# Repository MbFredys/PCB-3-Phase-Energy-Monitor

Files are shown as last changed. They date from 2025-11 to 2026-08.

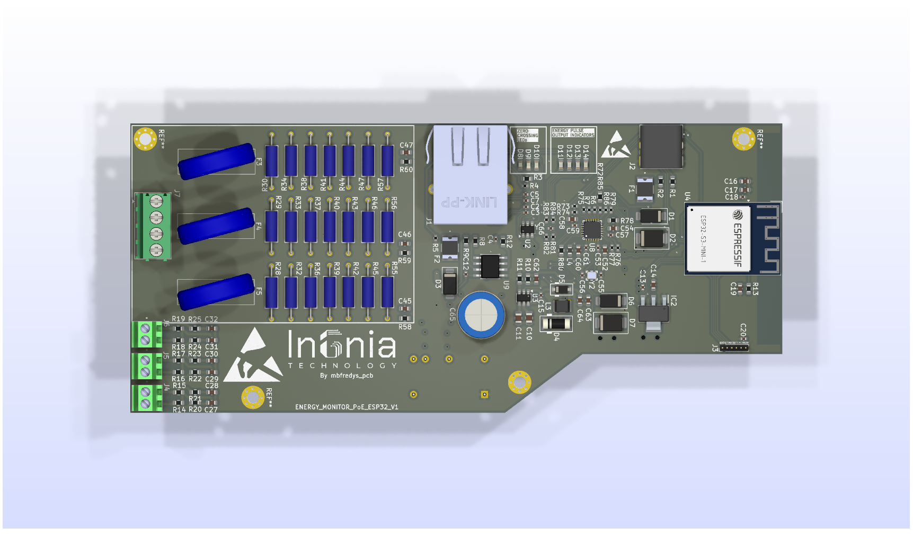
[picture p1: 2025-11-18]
Release/topview_2.png

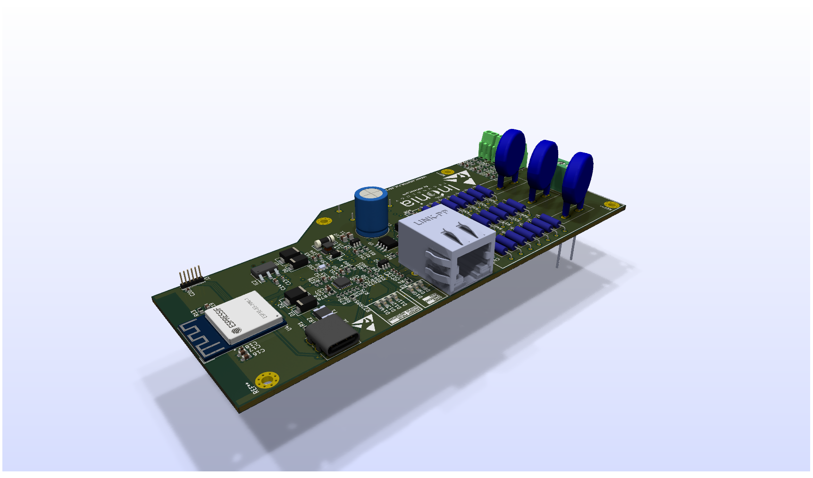
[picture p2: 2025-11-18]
Release/3dview_2.png

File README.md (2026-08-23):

# Three-Phase Energy Monitor



Hardware design for a three-phase, four-wire energy-monitoring platform with Ethernet and Power over Ethernet, intended for future integration with building-management systems.

> **Project status:** Design and manufacturing documentation completed. The PCB has not been fabricated, calibrated, electrically validated, or tested for regulatory compliance.

## Project objective

The project explores an open and documented architecture capable of acquiring three-phase electrical measurements and exposing them through a connected embedded platform.

## System architecture

- **Measurement:** ATM90E32AS for 3P4W energy measurement
- **Controller:** ESP32-S3-MINI-1
- **Networking:** LAN8720A Ethernet PHY using RMII
- **Power:** TPS2378 PoE interface with local 5 V and 3.3 V rails
- **Sensing:** External current transformers and resistive voltage-sensing networks
- **Isolation:** Digital isolators between measurement and low-voltage digital domains
- **Development access:** USB and debugging/programming interfaces

## Engineering work

- Defined system requirements and functional architecture
- Selected the principal ICs, protection devices, connectors, and power components
- Developed the schematic and multi-domain PCB layout in KiCad
- Defined measurement, isolation, Ethernet, PoE, and power-distribution sections
- Prepared the BOM and manufacturing documentation

## Key design considerations

- Isolation boundaries and return-current paths
- Creepage and clearance around mains-related circuitry
- Mixed-signal grounding and decoupling
- Ethernet differential routing and PHY termination
- PoE power conversion and protection
- Calibration strategy for voltage and current channels

## Deliverables

The repository contains the available design source files and supporting manufacturing documentation. Review the repository structure before using any generated outputs.

## Validation still required

A physical prototype is required to verify:

- Electrical safety and isolation distances
- Measurement accuracy and calibration
- Ethernet and PoE operation
- Thermal behavior and power integrity
- EMC/EMI performance
- Compliance with any applicable product or installation standards

This repository should be treated as an engineering design project, not as a certified or production-ready energy meter.

## License

Licensed under CERN-OHL-W-2.0.

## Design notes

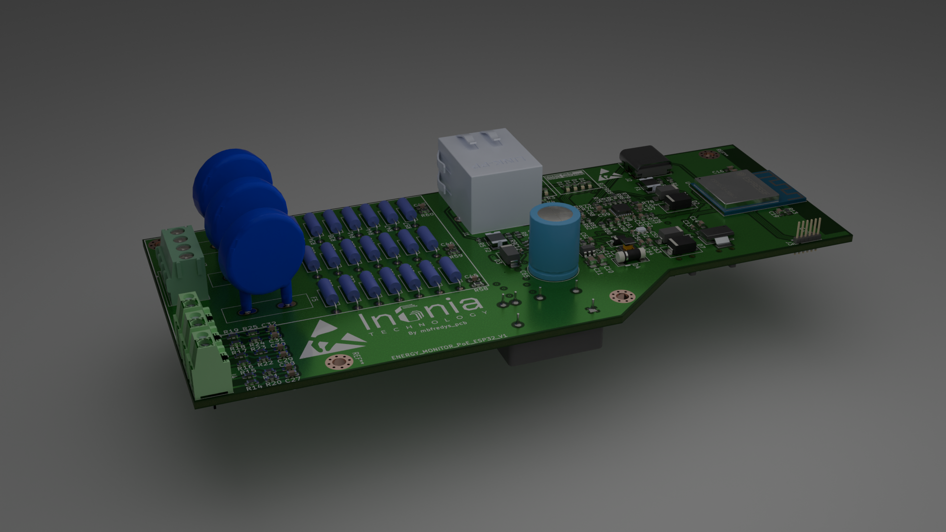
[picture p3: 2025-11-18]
Release/3D_HIGH_QUALITY.png

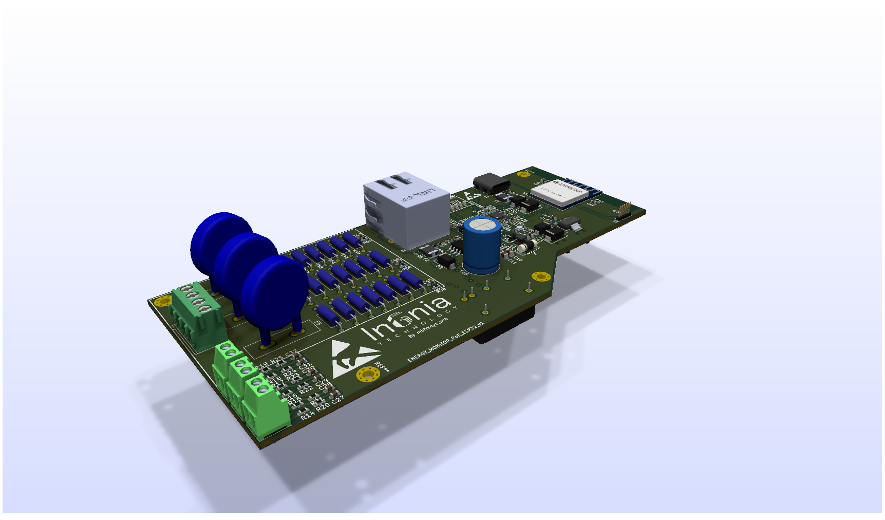
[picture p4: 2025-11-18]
Release/3dview.png

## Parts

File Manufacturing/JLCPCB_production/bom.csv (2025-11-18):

Designator | Footprint | Quantity | Value | LCSC Part #
C1, C12, C13, C15, C18, C20, C25, C26, C34, C35, C39, C4, C41, C42, C48, C49, C57, C66 | 0402 | 18 | 0.1uF
C10, C11 | 0805 | 2 | 10uF
C14, C16, C21, C36, C37, C43, C44, C50, C51, C54, C6, C63, C64 | 0603 | 13 | 10uF
C17, C19, C52, C58, C60 | 0603 | 5 | 1uF
C2, C23, C24, C3, C5, C55, C56, C7 | 0402 | 8 | 10pF
C22 | 0603 | 1 | 4.7uF
C27, C28, C29, C30, C31, C32, C33, C38, C40, C45, C46, C47 | 0603 | 12 | 18nF
C53, C59, C61 | 0402 | 3 | 470pF
C62 | 0603 | 1 | 20pF
C65 | C_Radial_D10.0mm_H12.5mm_P5.00mm | 1 | 22uF
C8, C9 | 0603 | 2 | 2.2uF
D1, D6 | D_SMA | 2 | SS14
D10, D11, D12, D13, D14, D8, D9 | 0603 | 7 | LEDs
D2, D7 | D_SMB_TVS | 2 | SMBJ5.0CA
D3 | D_SMA | 1 | SMAJ58A
D4 | D_MELF | 1 | SM360
D5 | D_SOD-123 | 1 | 1N4148W
F1 | FUSE_1812L05060_LTF | 1 | 1812L110PR
F2 | FUSE_1812L05060_LTF | 1 | 1812L050/60MR
F3, F4, F5 | MOV14D471K | 3 | MOV14D471K
IC1, IC2 | SOT230P700X180-4N | 2 | LD1117-3.3V
J1 | MagJack_PoE_RJ45 | 1 | RJ45_PoE
J2 | USB_C_Receptacle_GCT_USB4085 | 1 | USB_C_Receptacle_USB2.0_14P
J3 | PinHeader_1x06_P1.00mm_Vertical | 1 | Pin Header
J4, J5, J6 | TE_282834-2 | 3 | Screw_Terminal_01x02
J7 | TerminalBlock_Phoenix_PT-1,5-4-3.5-H_1x04_P3.50mm_Horizontal | 1 | Screw_Conn
L1, L2, L3 | FUSE_MF-USMFLAB | 3 | 22uH
L4 | 0603 | 1 | FerriteBead
R1, R2 | 0603 | 2 | 5.1k
R10 | 0603 | 1 | 52.3k
R11, R12, R13, R3, R31, R61, R78 | 0603 | 7 | 10k
R14, R15, R16, R17, R18, R19 | 0603 | 6 | 2.4
R20, R21, R22, R23, R24, R25, R26, R27, R35, R58, R59, R60 | 0603 | 12 | 1k
R28, R29, R30, R32, R33, R34, R36, R37, R38, R39, R40, R41, R42, R43, R44, R45, R46, R47, R55, R56, R57 | RES_09FCT00_VIS | 21 | 240k
R4, R5 | 0402 | 2 | 270
R48, R49, R50, R51, R6, R62, R63, R64, R7, R73, R74, R75, R76, R77, R79, R85, R86 | 0402 | 17 | 33
R52, R53, R54, R65, R66, R67, R68, R69, R70, R71 | 0402 | 10 | 510
R72 | 0603 | 1 | 2.2k
R8 | 0603 | 1 | 24.9k
R80 | 0603 | 1 | 12.1k
R81, R82, R83, R84 | 0402 | 4 | 50
R9 | 0603 | 1 | 63.4
SW1, SW2 | SW_SPDT_PCM12 | 2 | SW_SPDT
U1 | Converter_DCDC_Murata_NMAxxxxDC_THT | 1 | NMA0505DC
U2 | SOT-23-6 | 1 | WE-TVS-824015043
U3 | SOT-23-6 | 1 | MCP16331x-xCH
U4 | ESP32-S2-MINI-1 | 1 | ESP32-S3-MINI-1
U5 | TQFP48_7x7MC_MCH | 1 | ATM90E32AS-AU-Y
U6 | SOIC-16W_7.5x10.3mm_P1.27mm | 1 | Si8660ED-AS
U7 | SOIC-16W_7.5x10.3mm_P1.27mm | 1 | Si8641ED-B-IS
U8 | LAN8720A | 1 | LAN8720A
U9 | DDA8_3P1X2P4_TEX-M | 1 | TPS2378DDAR
Y1 | Crystal_SMD_2.0x1.6mm | 1 | 16MHz
Y2 | Crystal_SMD_2.0x1.6mm | 1 | 25MHz

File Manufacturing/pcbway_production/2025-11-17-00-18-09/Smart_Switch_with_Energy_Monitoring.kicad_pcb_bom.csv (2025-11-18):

Designator | Quantity | Value | Footprint | Package | MPN | DNP | Mount_Type
C1, C12, C13, C15, C18, C20, C25, C26, C34, C35, C39, C4, C41, C42, C48, C49, C57, C66 | 18 | 0.1uF | C_0402_1005Metric |  |  |  | smt
C10, C11 | 2 | 10uF | C_0805_2012Metric |  |  |  | smt
C14, C16, C21, C36, C37, C43, C44, C50, C51, C54, C6, C63, C64 | 13 | 10uF | C_0603_1608Metric |  |  |  | smt
C17, C19, C52, C58, C60 | 5 | 1uF | C_0603_1608Metric |  |  |  | smt
C2, C23, C24, C3, C5, C55, C56, C7 | 8 | 10pF | C_0402_1005Metric |  |  |  | smt
C22 | 1 | 4.7uF | C_0603_1608Metric |  |  |  | smt
C27, C28, C29, C30, C31, C32, C33, C38, C40, C45, C46, C47 | 12 | 18nF | C_0603_1608Metric |  |  |  | smt
C53, C59, C61 | 3 | 470pF | C_0402_1005Metric |  |  |  | smt
C62 | 1 | 20pF | C_0603_1608Metric |  |  |  | smt
C65 | 1 | 22uF | C_Radial_D10.0mm_H12.5mm_P5.00mm |  |  |  | tht
C8, C9 | 2 | 2.2uF | C_0603_1608Metric |  |  |  | smt
D1, D6 | 2 | SS14 | D_SMA |  |  |  | smt
D10, D11, D12, D13, D14, D8, D9 | 7 | LEDs | LED_0603_1608Metric |  |  |  | smt
D2, D7 | 2 | SMBJ5.0CA | D_SMB_TVS |  |  |  | smt
D3 | 1 | SMAJ58A | D_SMA |  |  |  | smt
D4 | 1 | SM360 | D_MELF |  |  |  | smt
D5 | 1 | 1N4148W | D_SOD-123 |  |  |  | smt
F1 | 1 | 1812L110PR | FUSE_1812L05060_LTF |  |  |  | smt
F2 | 1 | 1812L050/60MR | FUSE_1812L05060_LTF |  |  |  | smt
F3, F4, F5 | 3 | MOV14D471K | MOV14D471K |  |  |  | tht
IC1, IC2 | 2 | LD1117-3.3V | SOT230P700X180-4N |  |  |  | smt
J1 | 1 | RJ45_PoE | MagJack_PoE_RJ45 |  |  |  | tht
J2 | 1 | USB_C_Receptacle_USB2.0_14P | USB_C_Receptacle_GCT_USB4085 |  |  |  | tht
J3 | 1 | Pin Header | PinHeader_1x06_P1.00mm_Vertical |  |  |  | tht
J4, J5, J6 | 3 | Screw_Terminal_01x02 | TE_282834-2 |  |  |  | tht
J7 | 1 | Screw_Conn | TerminalBlock_Phoenix_PT-1,5-4-3.5-H_1x04_P3.50mm_Horizontal |  |  |  | tht
L1, L2, L3 | 3 | 22uH | FUSE_MF-USMFLAB |  |  |  | smt
L4 | 1 | FerriteBead | L_0603_1608Metric |  |  |  | smt
R1, R2 | 2 | 5.1k | R_0603_1608Metric |  |  |  | smt
R10 | 1 | 52.3k | R_0603_1608Metric |  |  |  | smt
R11, R12, R13, R3, R31, R61, R78 | 7 | 10k | R_0603_1608Metric |  |  |  | smt
R14, R15, R16, R17, R18, R19 | 6 | 2.4 | R_0603_1608Metric |  |  |  | smt
R20, R21, R22, R23, R24, R25, R26, R27, R35, R58, R59, R60 | 12 | 1k | R_0603_1608Metric |  |  |  | smt
R28, R29, R30, R32, R33, R34, R36, R37, R38, R39, R40, R41, R42, R43, R44, R45, R46, R47, R55, R56, R57 | 21 | 240k | RES_09FCT00_VIS |  |  |  | tht
R4, R5 | 2 | 270 | R_0402_1005Metric |  |  |  | smt
R48, R49, R50, R51, R6, R62, R63, R64, R7, R73, R74, R75, R76, R77, R79, R85, R86 | 17 | 33 | R_0402_1005Metric |  |  |  | smt
R52, R53, R54, R65, R66, R67, R68, R69, R70, R71 | 10 | 510 | R_0402_1005Metric |  |  |  | smt
R72 | 1 | 2.2k | R_0603_1608Metric |  |  |  | smt
R8 | 1 | 24.9k | R_0603_1608Metric |  |  |  | smt
R80 | 1 | 12.1k | R_0603_1608Metric |  |  |  | smt
R81, R82, R83, R84 | 4 | 50 | R_0402_1005Metric |  |  |  | smt
R9 | 1 | 63.4 | R_0603_1608Metric |  |  |  | smt
SW1, SW2 | 2 | SW_SPDT | SW_SPDT_PCM12 |  |  |  | smt
U1 | 1 | NMA0505DC | Converter_DCDC_Murata_NMAxxxxDC_THT |  |  |  | tht
U2 | 1 | WE-TVS-824015043 | SOT-23-6 |  |  |  | smt
U3 | 1 | MCP16331x-xCH | SOT-23-6 |  |  |  | smt
U4 | 1 | ESP32-S3-MINI-1 | ESP32-S2-MINI-1 |  |  |  | smt
U5 | 1 | ATM90E32AS-AU-Y | TQFP48_7x7MC_MCH |  |  |  | smt
U6 | 1 | Si8660ED-AS | SOIC-16W_7.5x10.3mm_P1.27mm |  |  |  | smt
U7 | 1 | Si8641ED-B-IS | SOIC-16W_7.5x10.3mm_P1.27mm |  |  |  | smt
U8 | 1 | LAN8720A | LAN8720A |  |  |  | smt
U9 | 1 | TPS2378DDAR | DDA8_3P1X2P4_TEX-M |  |  |  | smt
Y1 | 1 | 16MHz | Crystal_SMD_2.0x1.6mm |  |  |  | smt
Y2 | 1 | 25MHz | Crystal_SMD_2.0x1.6mm |  |  |  | smt

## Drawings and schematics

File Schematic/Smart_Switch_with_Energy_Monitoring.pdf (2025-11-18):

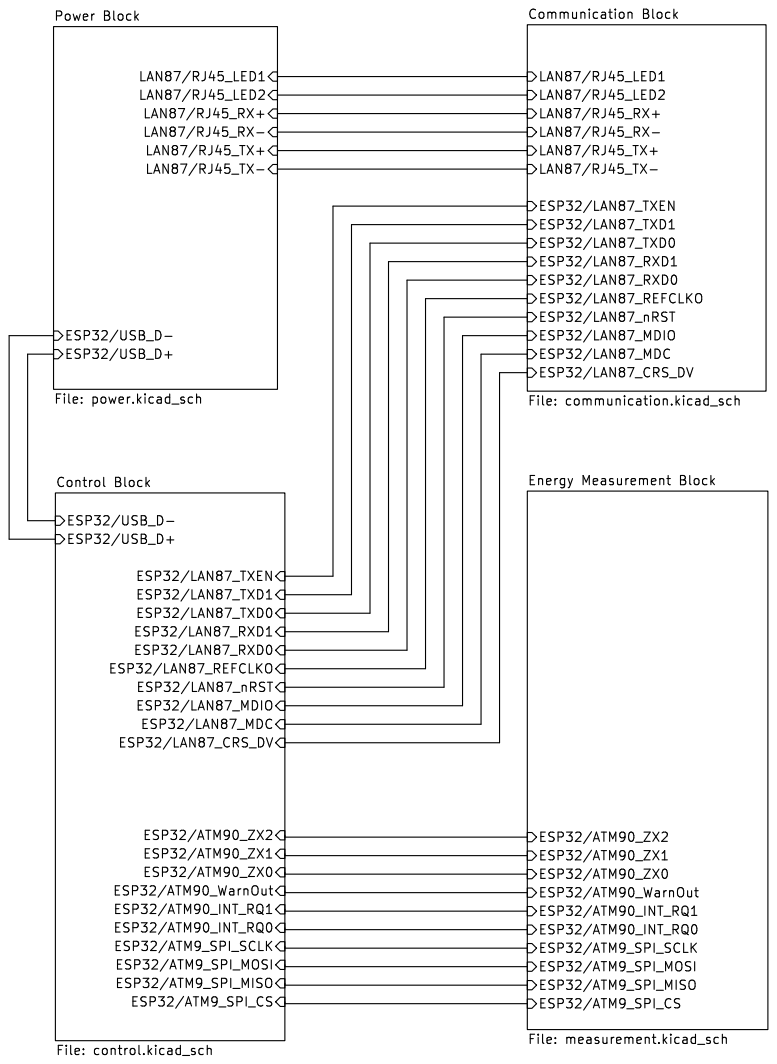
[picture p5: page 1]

Id: 1/5 Title: Office Energy Monitor File: Smart_Switch_with_Energy_Monitoring.kicad_sch Sheet: /

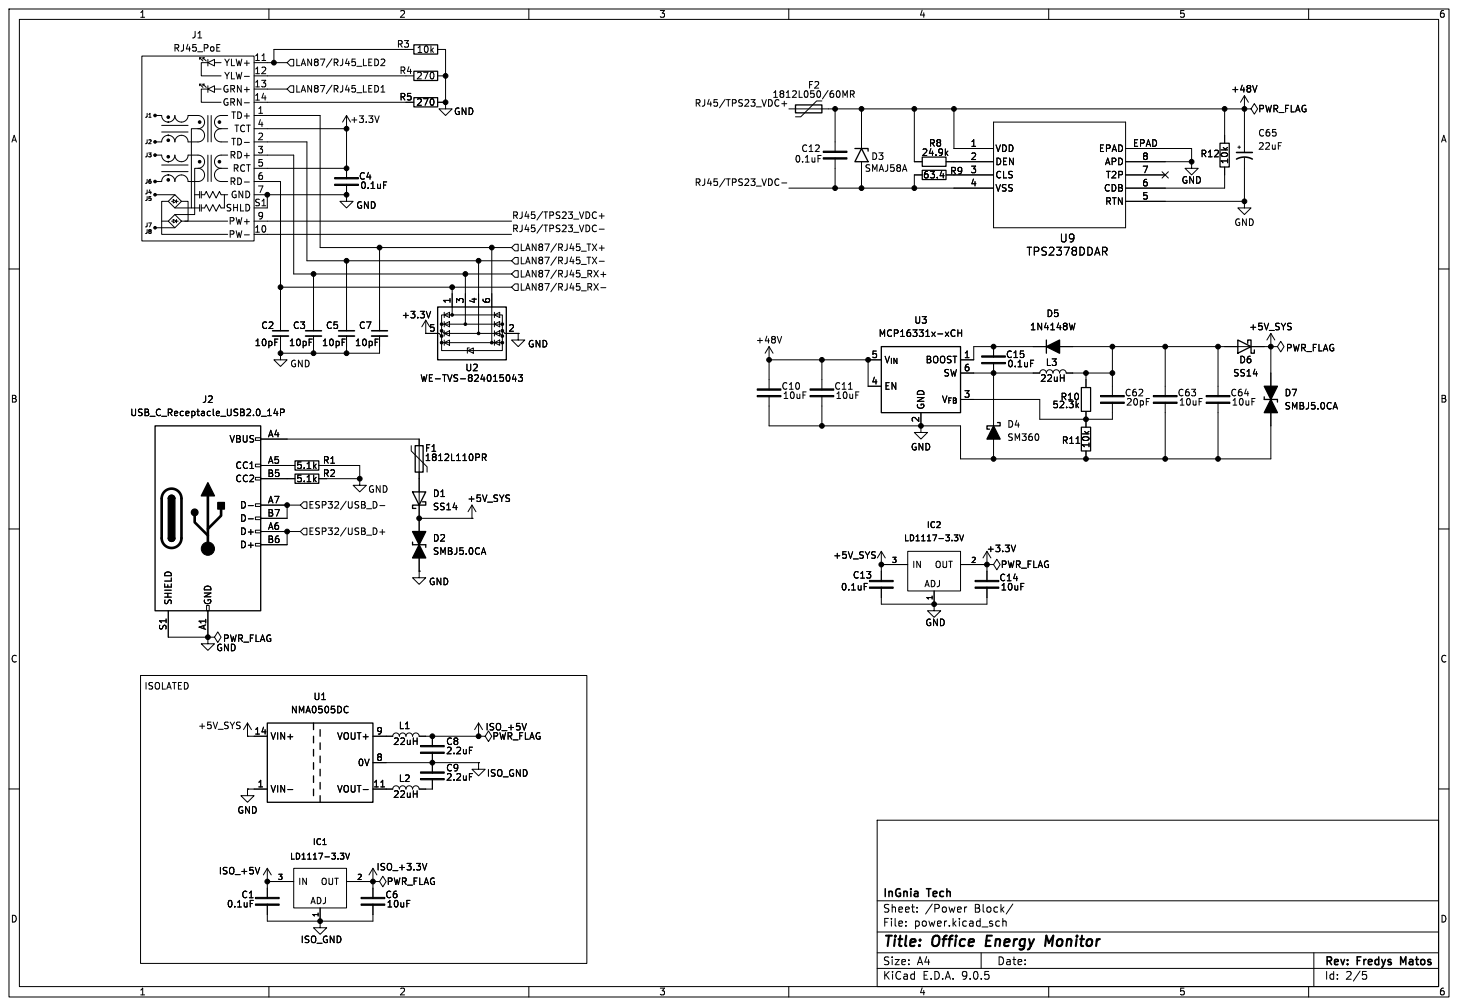
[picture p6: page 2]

2 BOOST 1 SW 6 V_{FB}3 U3 MCP16331x-xCH

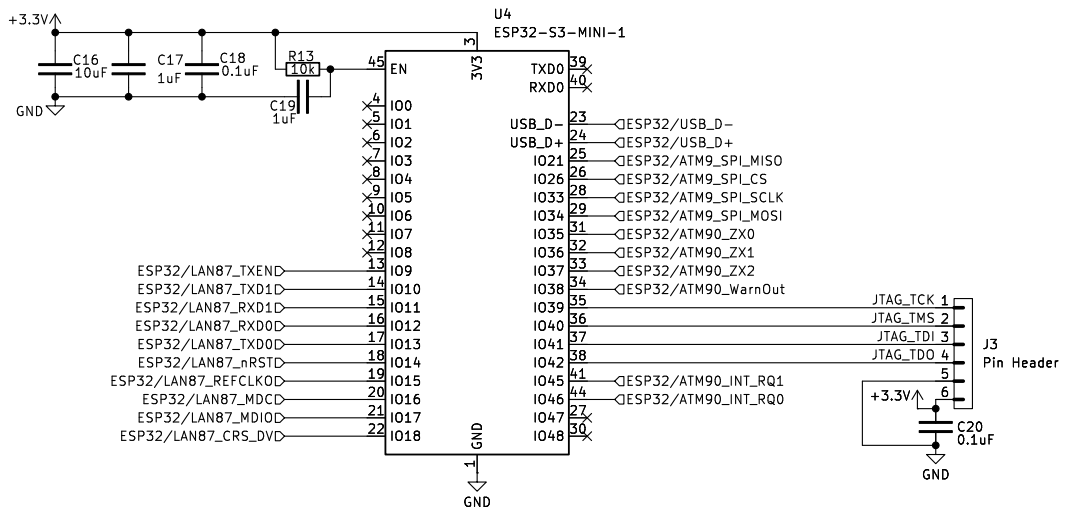
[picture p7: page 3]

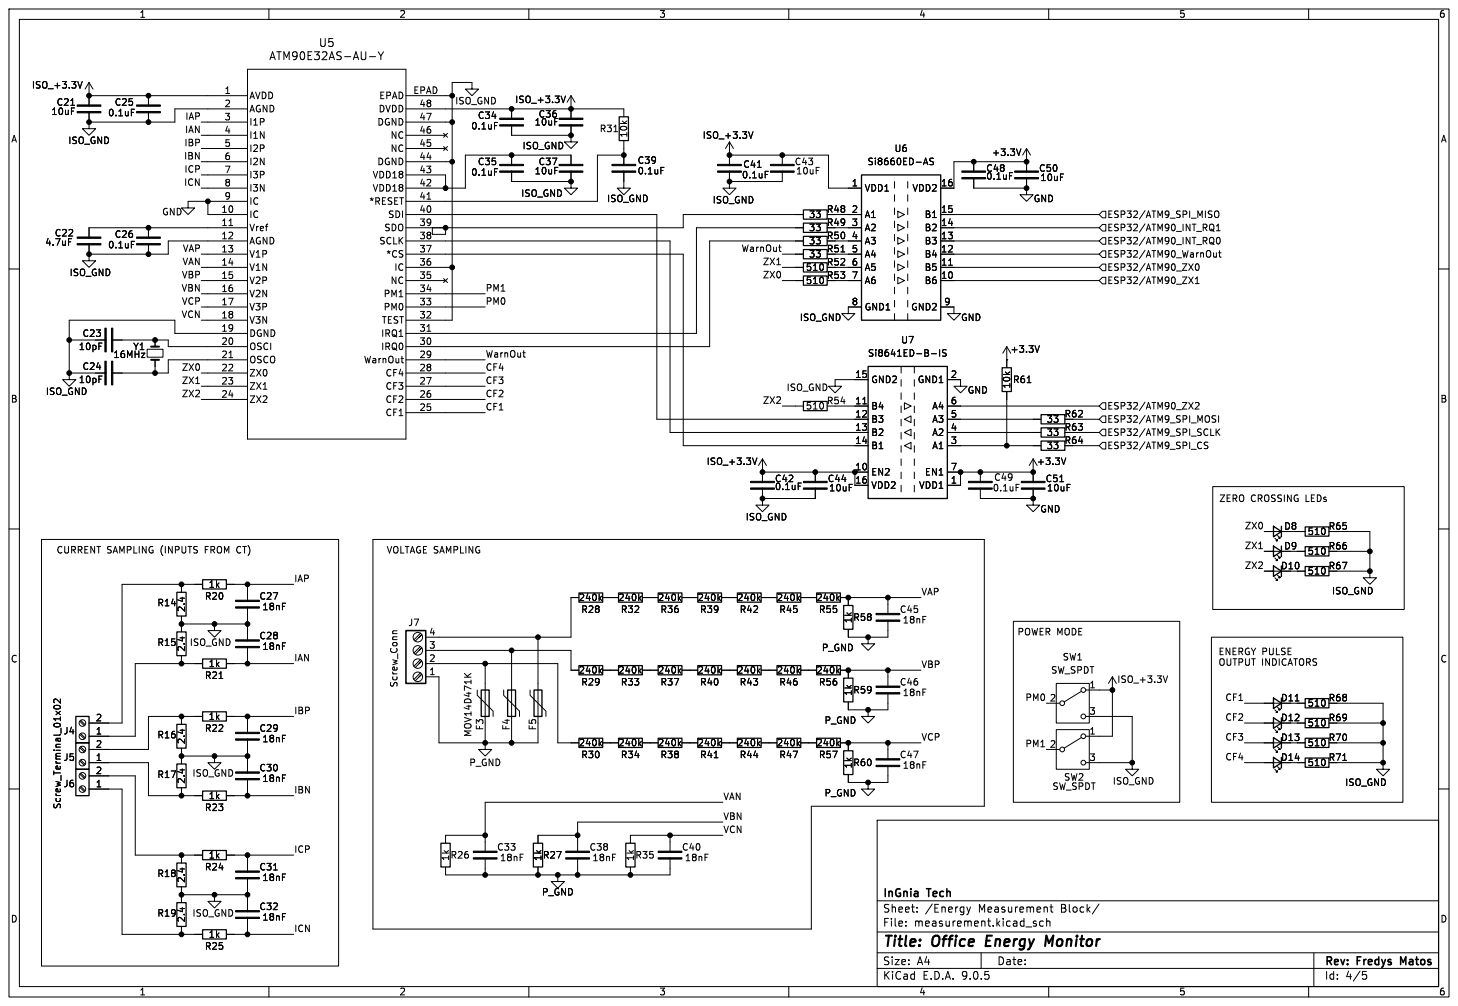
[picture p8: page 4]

ZERO CROSSING LEDs POWER MODE

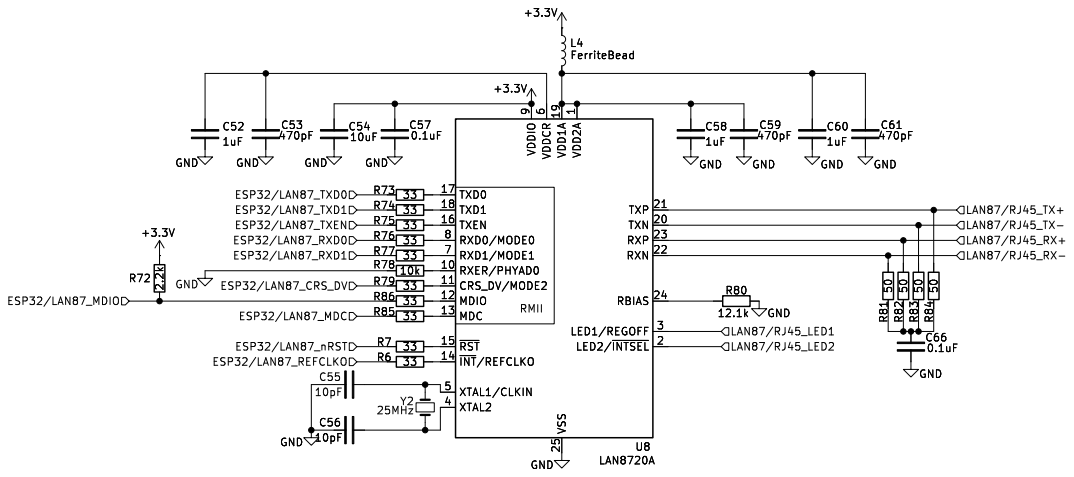
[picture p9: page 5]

1 TXP 21 TXN 20 RXP 23 RXN 22 RBIAS 24

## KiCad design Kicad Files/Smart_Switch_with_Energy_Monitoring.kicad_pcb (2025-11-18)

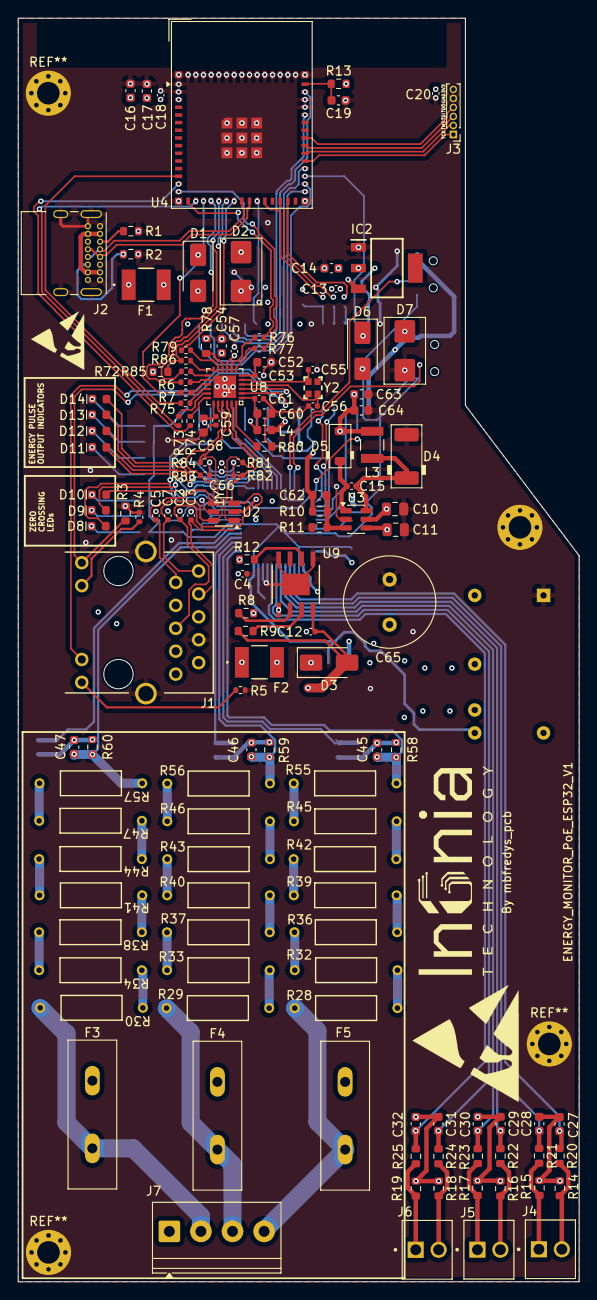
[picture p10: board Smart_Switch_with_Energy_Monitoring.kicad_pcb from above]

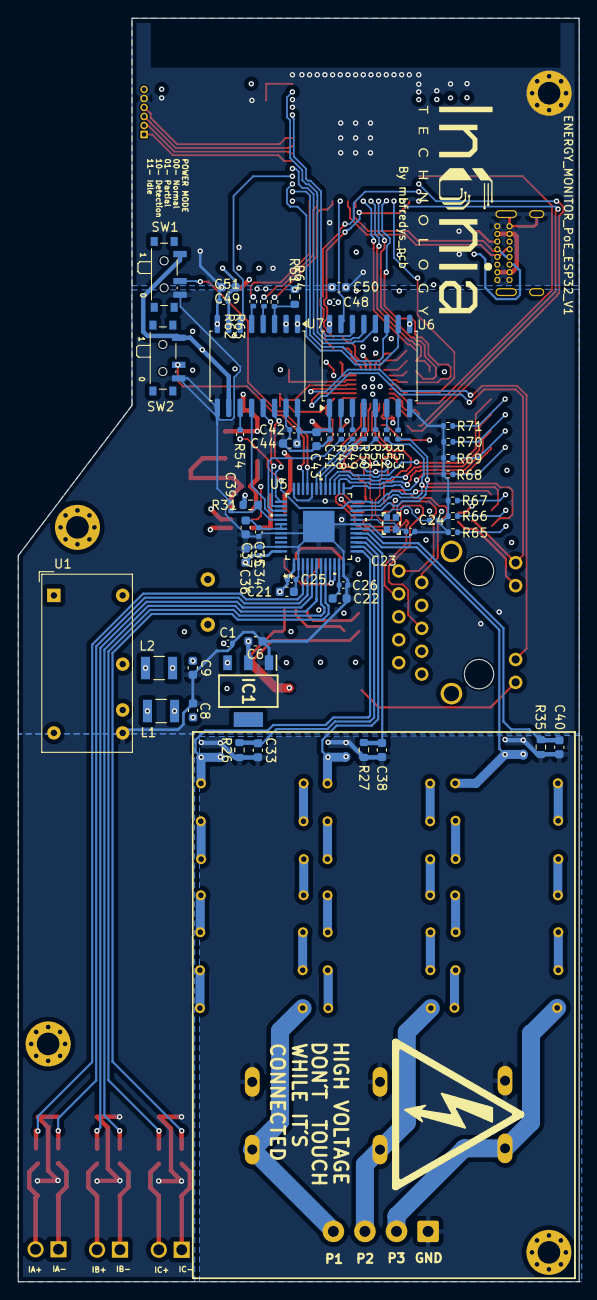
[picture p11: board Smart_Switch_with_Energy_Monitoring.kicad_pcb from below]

Board: 4 copper layers, 62.1 x 140.0 mm, 197 parts (58 on the bottom side), 153 nets.

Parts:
C1, C4, C12, C13, C15, C18, C20, C25, C26, C34, C35, C39, C41, C42, C48, C49, C57, C66: 0.1uF; C_0402_1005Metric
C2, C3, C5, C7, C23, C24, C55, C56: 10pF; C_0402_1005Metric
C6, C14, C16, C21, C36, C37, C43, C44, C50, C51, C54, C63, C64: 10uF; C_0603_1608Metric
C8, C9: 2.2uF; C_0603_1608Metric
C10, C11: 10uF; C_0805_2012Metric
C17, C19, C52, C58, C60: 1uF; C_0603_1608Metric
C22: 4.7uF; C_0603_1608Metric
C27, C28, C29, C30, C31, C32, C33, C38, C40, C45, C46, C47: 18nF; C_0603_1608Metric
C53, C59, C61: 470pF; C_0402_1005Metric
C62: 20pF; C_0603_1608Metric
C65: 22uF; C_Radial_D10.0mm_H12.5mm_P5.00mm
D1, D6: SS14; D_SMA
D2, D7: SMBJ5.0CA; D_SMB_TVS
D3: SMAJ58A; D_SMA
D4: SM360; D_MELF
D5: 1N4148W; D_SOD-123
D8, D9, D10, D11, D12, D13, D14: LEDs; LED_0603_1608Metric
F1: 1812L110PR; FUSE_1812L05060_LTF
F2: 1812L050/60MR; FUSE_1812L05060_LTF
F3, F4, F5: MOV14D471K
IC1, IC2: LD1117-3.3V; SOT230P700X180-4N
J1: RJ45_PoE; MagJack_PoE_RJ45
J2: USB_C_Receptacle_USB2.0_14P; USB_C_Receptacle_GCT_USB4085
J3: Pin Header; PinHeader_1x06_P1.00mm_Vertical
J4, J5, J6: Screw_Terminal_01x02; TE_282834-2
J7: Screw_Conn; TerminalBlock_Phoenix_PT-1,5-4-3.5-H_1x04_P3.50mm_Horizontal
L1, L2, L3: 22uH; FUSE_MF-USMFLAB
L4: FerriteBead; L_0603_1608Metric
R1, R2: 5.1k; R_0603_1608Metric
R3, R11, R12, R13, R31, R61, R78: 10k; R_0603_1608Metric
R4, R5: 270; R_0402_1005Metric
R6, R7, R48, R49, R50, R51, R62, R63, R64, R73, R74, R75, R76, R77, R79, R85, R86: 33; R_0402_1005Metric
R8: 24.9k; R_0603_1608Metric
R9: 63.4; R_0603_1608Metric
R10: 52.3k; R_0603_1608Metric
R14, R15, R16, R17, R18, R19: 2.4; R_0603_1608Metric
R20, R21, R22, R23, R24, R25, R26, R27, R35, R58, R59, R60: 1k; R_0603_1608Metric
R28, R29, R30, R32, R33, R34, R36, R37, R38, R39, R40, R41, R42, R43, R44, R45, R46, R47, R55, R56, R57: 240k; RES_09FCT00_VIS
R52, R53, R54, R65, R66, R67, R68, R69, R70, R71: 510; R_0402_1005Metric
R72: 2.2k; R_0603_1608Metric
R80: 12.1k; R_0603_1608Metric
R81, R82, R83, R84: 50; R_0402_1005Metric
SW1, SW2: SW_SPDT; SW_SPDT_PCM12
U1: NMA0505DC; Converter_DCDC_Murata_NMAxxxxDC_THT
U2: WE-TVS-824015043; SOT-23-6
U3: MCP16331x-xCH; SOT-23-6
U4: ESP32-S3-MINI-1; ESP32-S2-MINI-1
U5: ATM90E32AS-AU-Y; TQFP48_7x7MC_MCH
U6: Si8660ED-AS; SOIC-16W_7.5x10.3mm_P1.27mm
U7: Si8641ED-B-IS; SOIC-16W_7.5x10.3mm_P1.27mm
U8: LAN8720A
U9: TPS2378DDAR; DDA8_3P1X2P4_TEX-M
Y1: 16MHz; Crystal_SMD_2.0x1.6mm
Y2: 25MHz; Crystal_SMD_2.0x1.6mm

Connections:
+3.3V: C4.2, C14.2, C16.2, C17.2, C18.2, C20.2, C48.2, C49.2, C50.2, C51.2, C54.2, C57.2, IC2.2 (OUT), J1.4 (TCT), J1.5 (RCT), J3.6, L4.1, R13.2, R61.1, R72.2, U2.5 (VBUS), U4.3 (3V3), U6.16 (VDD2), U7.1 (VDD1), U7.7 (EN1), U8.9 (VDDIO)
+5V_SYS: C13.2, D1.1 (K), D2.2 (A), D6.1 (K), D7.2 (A), IC2.3 (IN), U1.14 (VIN+)
+48V: C10.2, C11.2, C12.2, C65.1, D3.1 (A1), F2.2, R8.1, R12.1, U3.4 (EN), U3.5 (V_{IN}), U9.1 (VDD)
/Communication Block/ESP32/LAN87_CRS_DV: R79.1, U4.22 (IO18)
/Communication Block/ESP32/LAN87_MDC: R85.1, U4.20 (IO16)
/Communication Block/ESP32/LAN87_MDIO: R72.1, R86.1, U4.21 (IO17)
/Communication Block/ESP32/LAN87_REFCLKO: R6.1, U4.19 (IO15)
/Communication Block/ESP32/LAN87_RXD0: R76.1, U4.16 (IO12)
/Communication Block/ESP32/LAN87_RXD1: R77.1, U4.15 (IO11)
/Communication Block/ESP32/LAN87_TXD0: R73.1, U4.17 (IO13)
/Communication Block/ESP32/LAN87_TXD1: R74.1, U4.14 (IO10)
/Communication Block/ESP32/LAN87_TXEN: R75.1, U4.13 (IO9)
/Communication Block/ESP32/LAN87_nRST: R7.1, U4.18 (IO14)
/Communication Block/LAN87/RJ45_LED1: J1.13 (GRN+), U8.3 (LED1/REGOFF)
/Communication Block/LAN87/RJ45_LED2: J1.11 (YLW+), R3.2, U8.2 (LED2/~INTSEL)
/Communication Block/LAN87/RJ45_RX+: C3.1, J1.3 (RD+), R82.2, U2.3 (I/O2), U8.23 (RXP)
/Communication Block/LAN87/RJ45_RX-: C2.1, J1.6 (RD-), R81.2, U2.1 (I/O1), U8.22 (RXN)
/Communication Block/LAN87/RJ45_TX+: C7.1, J1.1 (TD+), R84.2, U2.6 (I/O4), U8.21 (TXP)
/Communication Block/LAN87/RJ45_TX-: C5.1, J1.2 (TD-), R83.2, U2.4 (I/O3), U8.20 (TXN)
/Control Block/ESP32/ATM9_SPI_CS: R64.1, U4.26 (IO26)
/Control Block/ESP32/ATM9_SPI_MISO: U4.25 (IO21), U6.15 (B1)
/Control Block/ESP32/ATM9_SPI_MOSI: R62.1, U4.29 (IO34)
/Control Block/ESP32/ATM9_SPI_SCLK: R63.1, U4.28 (IO33)
/Control Block/ESP32/ATM90_INT_RQ0: U4.44 (IO46), U6.13 (B3)
/Control Block/ESP32/ATM90_INT_RQ1: U4.41 (IO45), U6.14 (B2)
/Control Block/ESP32/ATM90_WarnOut: U4.34 (IO38), U6.12 (B4)
/Control Block/ESP32/ATM90_ZX0: U4.31 (IO35), U6.11 (B5)
/Control Block/ESP32/ATM90_ZX1: U4.32 (IO36), U6.10 (B6)
/Control Block/ESP32/ATM90_ZX2: U4.33 (IO37), U7.6 (A4)
/Control Block/ESP32/USB_D+: J2.A7 (D-), J2.B7 (D-), U4.24 (USB_D+)
/Control Block/ESP32/USB_D-: J2.A6 (D+), J2.B6 (D+), U4.23 (USB_D-)
/Control Block/JTAG_TCK: J3.1, U4.35 (IO39)
/Control Block/JTAG_TDI: J3.3, U4.37 (IO41)
/Control Block/JTAG_TDO: J3.4, U4.38 (IO42)
/Control Block/JTAG_TMS: J3.2, U4.36 (IO40)
/Energy Measurement Block/CF1: D11.2 (A), U5.25 (CF1)
/Energy Measurement Block/CF2: D12.2 (A), U5.26 (CF2)
/Energy Measurement Block/CF3: D13.2 (A), U5.27 (CF3)
/Energy Measurement Block/CF4: D14.2 (A), U5.28 (CF4)
/Energy Measurement Block/IAN: C28.2, R21.1, U5.4 (I1N)
/Energy Measurement Block/IAP: C27.1, R20.1, U5.3 (I1P)
/Energy Measurement Block/IBN: C30.2, R23.1, U5.6 (I2N)
/Energy Measurement Block/IBP: C29.1, R22.1, U5.5 (I2P)
/Energy Measurement Block/ICN: C32.2, R25.1, U5.8 (I3N)
/Energy Measurement Block/ICP: C31.1, R24.1, U5.7 (I3P)
/Energy Measurement Block/PM0: SW1.2 (B), U5.33 (PM0)
/Energy Measurement Block/PM1: SW2.2 (B), U5.34 (PM1)
/Energy Measurement Block/VAN: C33.1, R26.2, U5.14 (V1N)
/Energy Measurement Block/VAP: C45.1, R55.1, R58.2, U5.13 (V1P)
/Energy Measurement Block/VBN: C38.1, R27.2, U5.16 (V2N)
/Energy Measurement Block/VBP: C46.1, R56.1, R59.2, U5.15 (V2P)
/Energy Measurement Block/VCN: C40.1, R35.2, U5.18 (V3N)
/Energy Measurement Block/VCP: C47.1, R57.1, R60.2, U5.17 (V3P)
/Energy Measurement Block/WarnOut: R51.2, U5.29 (WarnOut)
/Energy Measurement Block/ZX0: D8.2 (A), R53.2, U5.22 (ZX0)
/Energy Measurement Block/ZX1: D9.2 (A), R52.2, U5.23 (ZX1)
/Energy Measurement Block/ZX2: D10.2 (A), R54.2, U5.24 (ZX2)
/Power Block/RJ45/TPS23_VDC+: F2.1, J1.9 (PW+)
/Power Block/RJ45/TPS23_VDC-: C12.1, D3.2 (A2), J1.10 (PW-), R9.1, U9.4 (VSS)
GND: C2.2, C3.2, C4.1, C5.2, C7.2, C10.1, C11.1, C13.1, C14.1, C16.1, C17.1, C18.1, C19.1, C20.1, C48.1, C49.1, C50.1, C51.1, C52.1, C53.2, C54.1, C55.1, C56.1, C57.1, C58.1, C59.2, C60.1, C61.2, C63.1, C64.1, C65.2, C66.1, D2.1 (K), D4.2 (A), D7.1 (K), IC2.1 (ADJ), J1.7 (GND), J1.S1 (SHLD), J1.S2 (SHLD), J2.A1 (GND), J2.A12 (GND), J2.B1 (GND), J2.B12 (GND), J2.S1 (SHIELD), J3.5, R1.2, R2.2, R3.1, R4.2, R5.2, R11.2, R78.2, R80.1, U1.1 (VIN-), U2.2 (GND), U3.2 (GND), U4.1 (GND), U4.2 (GND), U4.42 (GND), U4.43 (GND), U4.46 (GND), U4.47 (GND), U4.48 (GND), U4.49 (GND), U4.50 (GND), U4.51 (GND), U4.52 (GND), U4.53 (GND), U4.54 (GND), U4.55 (GND), U4.56 (GND), U4.57 (GND), U4.58 (GND), U4.59 (GND), U4.60 (GND), U4.61 (GND), U4.62 (GND), U4.63 (GND), U4.64 (GND), U4.65 (GND), U5.9 (IC), U5.10 (IC), U6.9 (GND2), U7.2 (GND1), U7.8 (GND1), U8.25 (VSS), U9.5 (RTN), U9.8 (APD), U9.EPAD
ISO_+3.3V: C6.2, C21.2, C25.2, C34.2, C36.2, C41.2, C42.2, C43.2, C44.2, IC1.2 (OUT), R31.1, SW1.1 (A), SW2.1 (A), U5.1 (AVDD), U5.48 (DVDD), U6.1 (VDD1), U7.10 (EN2), U7.16 (VDD2)
ISO_+5V: C1.2, C8.1, IC1.3 (IN), L1.2
ISO_GND: C1.1, C6.1, C8.2, C9.1, C21.1, C22.2, C23.1, C24.1, C25.1, C26.1, C27.2, C28.1, C29.2, C30.1, C31.2, C32.1, C34.1, C35.1, C36.1, C37.1, C39.1, C41.1, C42.1, C43.1, C44.1, IC1.1 (ADJ), R14.1, R15.2, R16.1, R17.2, R18.1, R19.2, R65.1, R66.1, R67.1, R68.1, R69.1, R70.1, R71.1, SW1.3 (C), SW2.3 (C), U1.8 (0V), U5.2 (AGND), U5.12 (AGND), U5.19 (DGND), U5.32 (TEST), U5.36 (IC), U5.44 (DGND), U5.47 (DGND), U5.EPAD, U6.8 (GND1), U7.9 (GND2), U7.15 (GND2)
unnamed: C9.2, L2.2
unnamed: C35.2, C37.2, U5.42 (VDD18), U5.43 (VDD18)
unnamed: C66.2, R81.1, R82.1, R83.1, R84.1
unnamed: D1.2 (A), F1.2
unnamed: C15.1, D4.1 (K), L3.1, U3.6 (SW)
unnamed: C62.2, C63.2, C64.2, D5.2 (A), D6.2 (A), L3.2, R10.2
unnamed: C15.2, D5.1 (K), U3.1 (BOOST)
unnamed: D8.1 (K), R65.2
unnamed: D9.1 (K), R66.2
unnamed: D10.1 (K), R67.2
unnamed: D11.1 (K), R68.2
unnamed: D12.1 (K), R69.2
unnamed: D13.1 (K), R70.2
unnamed: D14.1 (K), R71.2
unnamed: F1.1, J2.A4 (VBUS), J2.A9 (VBUS), J2.B4 (VBUS), J2.B9 (VBUS)
unnamed: F3.2, J7.2, R30.2
unnamed: F4.2, J7.3, R29.2
unnamed: F5.2, J7.4, R28.2
unnamed: J1.14 (GRN-), R5.1
unnamed: J1.12 (YLW-), R4.1
unnamed: J2.A5 (CC1), R1.1
unnamed: J2.B5 (CC2), R2.1
unnamed: J4.1, R15.1, R21.2
unnamed: J4.2, R14.2, R20.2
unnamed: J5.1, R17.1, R23.2
unnamed: J5.2, R16.2, R22.2
unnamed: J6.1, R19.1, R25.2
unnamed: J6.2, R18.2, R24.2
unnamed: R28.1, R32.2
unnamed: R29.1, R33.2
unnamed: R30.1, R34.2
unnamed: R32.1, R36.2
unnamed: R33.1, R37.2
unnamed: R34.1, R38.2
unnamed: R36.1, R39.2
unnamed: R37.1, R40.2
unnamed: R38.1, R41.2
unnamed: R39.1, R42.2
unnamed: R40.1, R43.2
unnamed: R41.1, R44.2
unnamed: R42.1, R45.2
unnamed: R43.1, R46.2
unnamed: R44.1, R47.2
unnamed: R45.1, R55.2
unnamed: R46.1, R56.2
unnamed: R47.1, R57.2
unnamed: L1.1, U1.9 (VOUT+)
unnamed: L2.1, U1.11 (VOUT-)
unnamed: C62.1, R10.1, R11.1, U3.3 (V_{FB})
unnamed: C19.2, R13.1, U4.45 (EN)
unnamed: U5.37 (*CS), U7.14 (B1)
unnamed: C39.2, R31.2, U5.41 (*RESET)
unnamed: R50.2, U5.30 (IRQ0)
unnamed: R49.2, U5.31 (IRQ1)
unnamed: C23.2, U5.20 (OSCI), Y1.1
unnamed: C24.2, U5.21 (OSCO), Y1.2
unnamed: U5.38 (SCLK), U7.13 (B2)
unnamed: U5.40 (SDI), U7.12 (B3)
unnamed: R48.2, U5.39 (SDO)
unnamed: C22.1, C26.2, U5.11 (Vref)
unnamed: R48.1, U6.2 (A1)
unnamed: R49.1, U6.3 (A2)
unnamed: R50.1, U6.4 (A3)
unnamed: R51.1, U6.5 (A4)
unnamed: R52.1, U6.6 (A5)
unnamed: R53.1, U6.7 (A6)
unnamed: R61.2, R64.2, U7.3 (A1)
unnamed: R63.2, U7.4 (A2)
unnamed: R62.2, U7.5 (A3)
unnamed: R54.1, U7.11 (B4)
unnamed: R79.2, U8.11 (CRS_DV/MODE2)
unnamed: R85.2, U8.13 (MDC)
unnamed: R86.2, U8.12 (MDIO)
unnamed: R80.2, U8.24 (RBIAS)
unnamed: R76.2, U8.8 (RXD0/MODE0)
unnamed: R77.2, U8.7 (RXD1/MODE1)
unnamed: R78.1, U8.10 (RXER/PHYAD0)
unnamed: R73.2, U8.17 (TXD0)
unnamed: R74.2, U8.18 (TXD1)
unnamed: R75.2, U8.16 (TXEN)
unnamed: C58.2, C59.1, C60.2, C61.1, L4.2, U8.1 (VDD2A), U8.19 (VDD1A)
unnamed: C52.2, C53.1, U8.6 (VDDCR)
unnamed: C55.2, U8.5 (XTAL1/CLKIN), Y2.1
unnamed: C56.2, U8.4 (XTAL2), Y2.2
unnamed: R6.2, U8.14 (~INT/REFCLKO)
unnamed: R7.2, U8.15 (~RST)
unnamed: R12.2, U9.6 (CDB)
unnamed: R9.2, U9.3 (CLS)
unnamed: R8.2, U9.2 (DEN)
P_GND: C33.2, C38.2, C40.2, C45.2, C46.2, C47.2, F3.1, F4.1, F5.1, J7.1, R26.1, R27.1, R35.1, R58.1, R59.1, R60.1

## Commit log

2025-11-18 Revise README for Energy Monitoring PCB project
    Updated project description, features, and usage instructions in README.md for clarity and detail.
2025-11-18 Simplify power architecture description in README

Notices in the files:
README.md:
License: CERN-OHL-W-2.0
